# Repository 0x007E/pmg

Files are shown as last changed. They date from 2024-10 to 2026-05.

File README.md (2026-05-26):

  

# `PMG` - Audio Level Meter (Pegelmessgerät)

The `pmg` project is based on a pcb with an elektret microphone signal transistor (`BC547`) amplifier and a transistor stage for level signalization.

| Experience | Level |
|:---|:-----:|
| Soldering | 50% |
| Mechanical  | 50% |

# Downloads

| Type | File | Description |
|:---:|:---:|:---|
| Simulation | [asc](https://github.com/0x007E/pmg/raw/refs/heads/main/PMG.asc) | LTSpice Simulation | 
| Lochmaster | [lm4](https://github.com/0x007E/pmg/raw/refs/heads/main/PMG.LM4) | Stripe grid circuit board | 
| Schematic | [pdf](https://github.com/0x007E/pmg/releases/latest/download/schematic.pdf) / [cadlab](https://cadlab.io/project/28569/main/files) | Schematic files |
| Board | [pdf](https://github.com/0x007E/pmg/releases/latest/download/pcb.pdf) / [cadlab](https://cadlab.io/project/28569/main/files) | Board file |
| Drill | [pdf](https://github.com/0x007E/pmg/releases/latest/download/drill.pdf) | Drill file |
| BoM | [xlsx](https://github.com/0x007E/pmg/releases/latest/download/bom.xlsx) / [html](https://github.com/0x007E/pmg/releases/latest/download/bom.html) | Bill of Material as Excel/interactive HTML |
| PCB | [zip](https://github.com/0x007E/pmg/releases/latest/download/kicad.zip) / [tar](https://github.com/0x007E/pmg/releases/latest/download/kicad.tar.gz) | KiCAD/Gerber/BoM/Drill files |
| Mechanical | [zip](https://github.com/0x007E/pmg/releases/latest/download/freecad.zip) / [tar](https://github.com/0x007E/pmg/releases/latest/download/freecad.tar.gz) | FreeCAD/Housing and PCB (STEP/STL) files |

# Hardware

There are two parts of the hardware. The pcb and the housing of the `PMG`. The pcb is created with `KiCAD` and the housing with `FreeCAD`. All files are built with `github actions` so that they are ready for a production environment. The housing is printed with a 3D-printer (`Dremel 3D40`).

## PCB

The circuit board is populated on one side (Top). The best way for soldering is within a standard soldering system.

### Top Layer

Top Layer

### Bottom Layer

Bottom Layer

## Mechanical

The housing has a tolerance of `0.2mm` on each side of the case. So the pcb should fit perfectly in the housing. The tolerance can be modified with `FreeCAD` in the `Parameter` Spreadsheet.

### Assembled

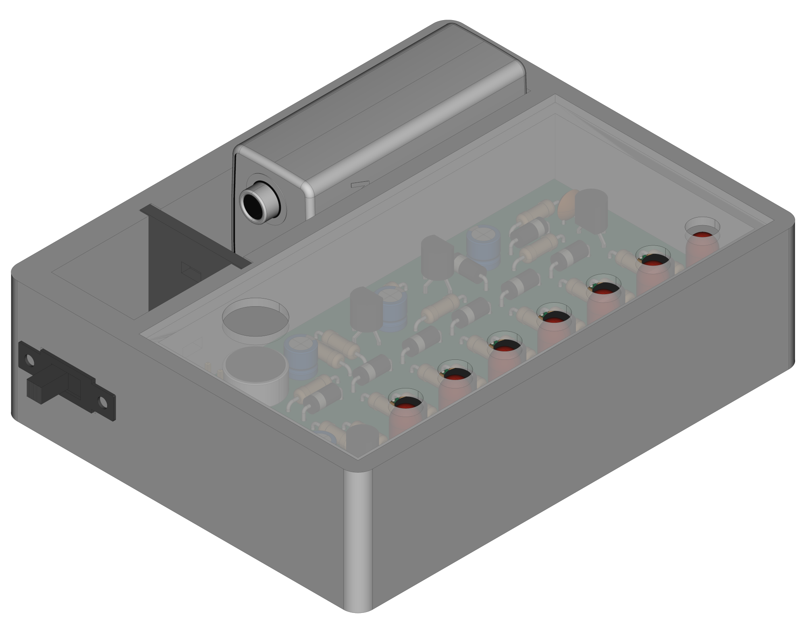
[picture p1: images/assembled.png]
Assembled


#### Exploded

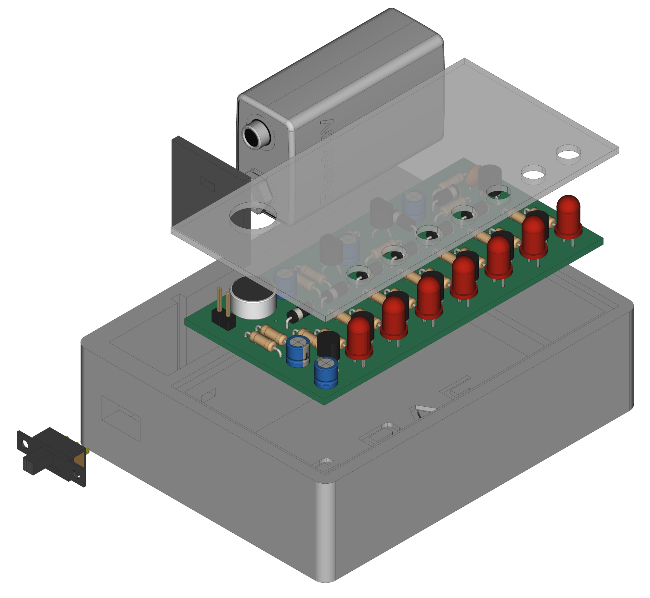
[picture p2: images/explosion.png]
Exploded


# Additional Information

| Type | Link | Description |
|:---:|:---:|:---|
| BC547 | [pdf](https://www.sparkfun.com/datasheets/Components/BC546.pdf) | NPN Transistor |

---

R. GAECHTER

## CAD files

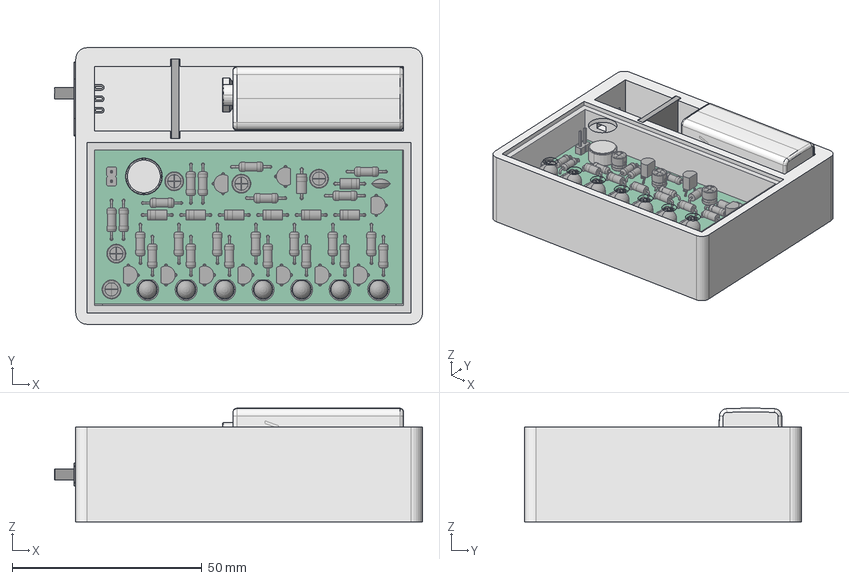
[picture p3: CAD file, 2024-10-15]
mechanical/housing.FCStd
97.1 x 73.0 x 30.0 mm
AcrylGlass
Separator
Switch
9VBlock
Pcb_1d7d
Q7_TO-92_Wide_4bfbe9c5f8f4
C6_C_Disc_D50mm_W25mm_P250mm_441e31f26d57
D14_D_A-405_P7.62mm_Horizontal_84994ef9fd34
R22_R_Axial_DIN0207_L63mm_D25mm_P1016mm_Horizontal_d8874ca5abab
R15_R_Axial_DIN0207_L63mm_D25mm_P1016mm_Horizontal_26bb8defbff6
D3_LED_D5.0mm_3ee2d2edeb13
Q8_TO-92_Wide_a93fba4ea393
Q1_TO-92_Wide_c0447f71f260
D4_LED_D5.0mm_dc1b8127458c
Q9_TO-92_Wide_263e551227a1
R14_R_Axial_DIN0207_L63mm_D25mm_P1016mm_Horizontal_b1f9f71ed35f
R13_R_Axial_DIN0207_L63mm_D25mm_P1016mm_Horizontal_caadc2475899
R8_R_Axial_DIN0207_L63mm_D25mm_P1016mm_Horizontal_83ed933a83d2
R2_R_Axial_DIN0207_L63mm_D25mm_P1016mm_Horizontal_2cb8f415b4d6
R1_R_Axial_DIN0207_L63mm_D25mm_P1016mm_Horizontal_401779ecf60e
MK1_CUI_DEVICES_CMA-4544PF-W_7a05e5a25c01
D15_D_A-405_P7.62mm_Horizontal_00f129ff81aa
D12_D_A-405_P7.62mm_Horizontal_3dac00b416f9
Q5_TO-92_Wide_fe35382576d2
Q6_TO-92_Wide_d52b6dc564fe
R12_R_Axial_DIN0207_L63mm_D25mm_P1016mm_Horizontal_3b9f8811e661
D11_D_A-405_P7.62mm_Horizontal_5c6651d95b19
R3_R_Axial_DIN0207_L63mm_D25mm_P1016mm_Horizontal_a9c3d9380691
D6_LED_D5.0mm_595b68b19a06
R20_R_Axial_DIN0207_L63mm_D25mm_P1016mm_Horizontal_8b5b8a0e60e4
R18_R_Axial_DIN0207_L63mm_D25mm_P1016mm_Horizontal_3c62972e58e7
D5_LED_D5.0mm_60034bc3a21b
C1_CP_Radial_D50mm_P250mm_23c4ec5917c1
C2_CP_Radial_D50mm_P250mm_5b7aa9b1d5d5
R21_R_Axial_DIN0207_L63mm_D25mm_P1016mm_Horizontal_043bab5f4419
C5_CP_Radial_D50mm_P250mm_fa609370bd94
R6_R_Axial_DIN0207_L63mm_D25mm_P1016mm_Horizontal_0dea557aebe9
R7_R_Axial_DIN0207_L63mm_D25mm_P1016mm_Horizontal_5a96a4f1f65e
R4_R_Axial_DIN0207_L63mm_D25mm_P1016mm_Horizontal_78e21f6ad2d1
Q4_TO-92_Wide_d99fa3e43c21
R16_R_Axial_DIN0207_L63mm_D25mm_P1016mm_Horizontal_4811e6ad3072
C3_CP_Radial_D50mm_P250mm_dfde33150532
J3_PinHeader_1x02_P254mm_Vertical_e5993ac934dd
R9_R_Axial_DIN0207_L63mm_D25mm_P1016mm_Horizontal_532797f5b529
D9_D_A-405_P7.62mm_Horizontal_a4ace171a1cc
R19_R_Axial_DIN0207_L63mm_D25mm_P1016mm_Horizontal_3230d582ee0a
R10_R_Axial_DIN0207_L63mm_D25mm_P1016mm_Horizontal_891c64406b5c
R17_R_Axial_DIN0207_L63mm_D25mm_P1016mm_Horizontal_3e8b808dfa95
Q3_TO-92_Wide_e69642412aa5
D2_LED_D5.0mm_370cab26fe4a
Q10_TO-92_Wide_6694c14d1b8c
D7_LED_D5.0mm_994bed6c4edc
D8_D_A-405_P7.62mm_Horizontal_a44a823cf9d3
R11_R_Axial_DIN0207_L63mm_D25mm_P1016mm_Horizontal_5143b20dbc7e
Q2_TO-92_Wide_83d40f09d7ee
D10_D_A-405_P7.62mm_Horizontal_c6f234e0c10f
R23_R_Axial_DIN0207_L63mm_D25mm_P1016mm_Horizontal_4c4d199288b2
D1_LED_D5.0mm_5167b579a80a
C4_CP_Radial_D50mm_P250mm_2689a81529ee
R5_R_Axial_DIN0207_L63mm_D25mm_P1016mm_Horizontal_431b73a015bb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

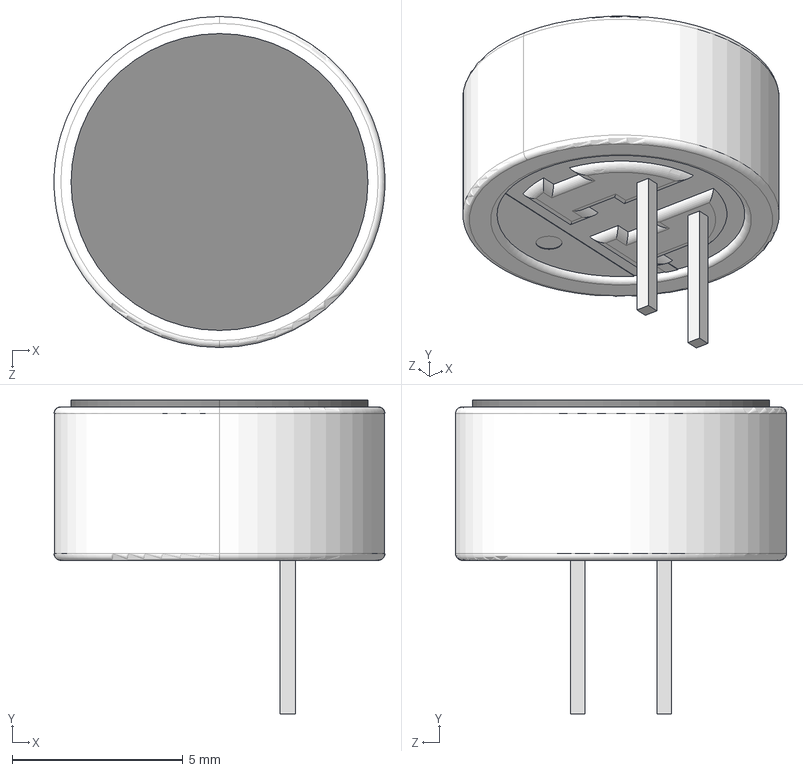
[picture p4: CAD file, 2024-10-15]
pcb/CUI_DEVICES_CMA-4544PF-W.step
9.70 x 9.20 x 9.70 mm

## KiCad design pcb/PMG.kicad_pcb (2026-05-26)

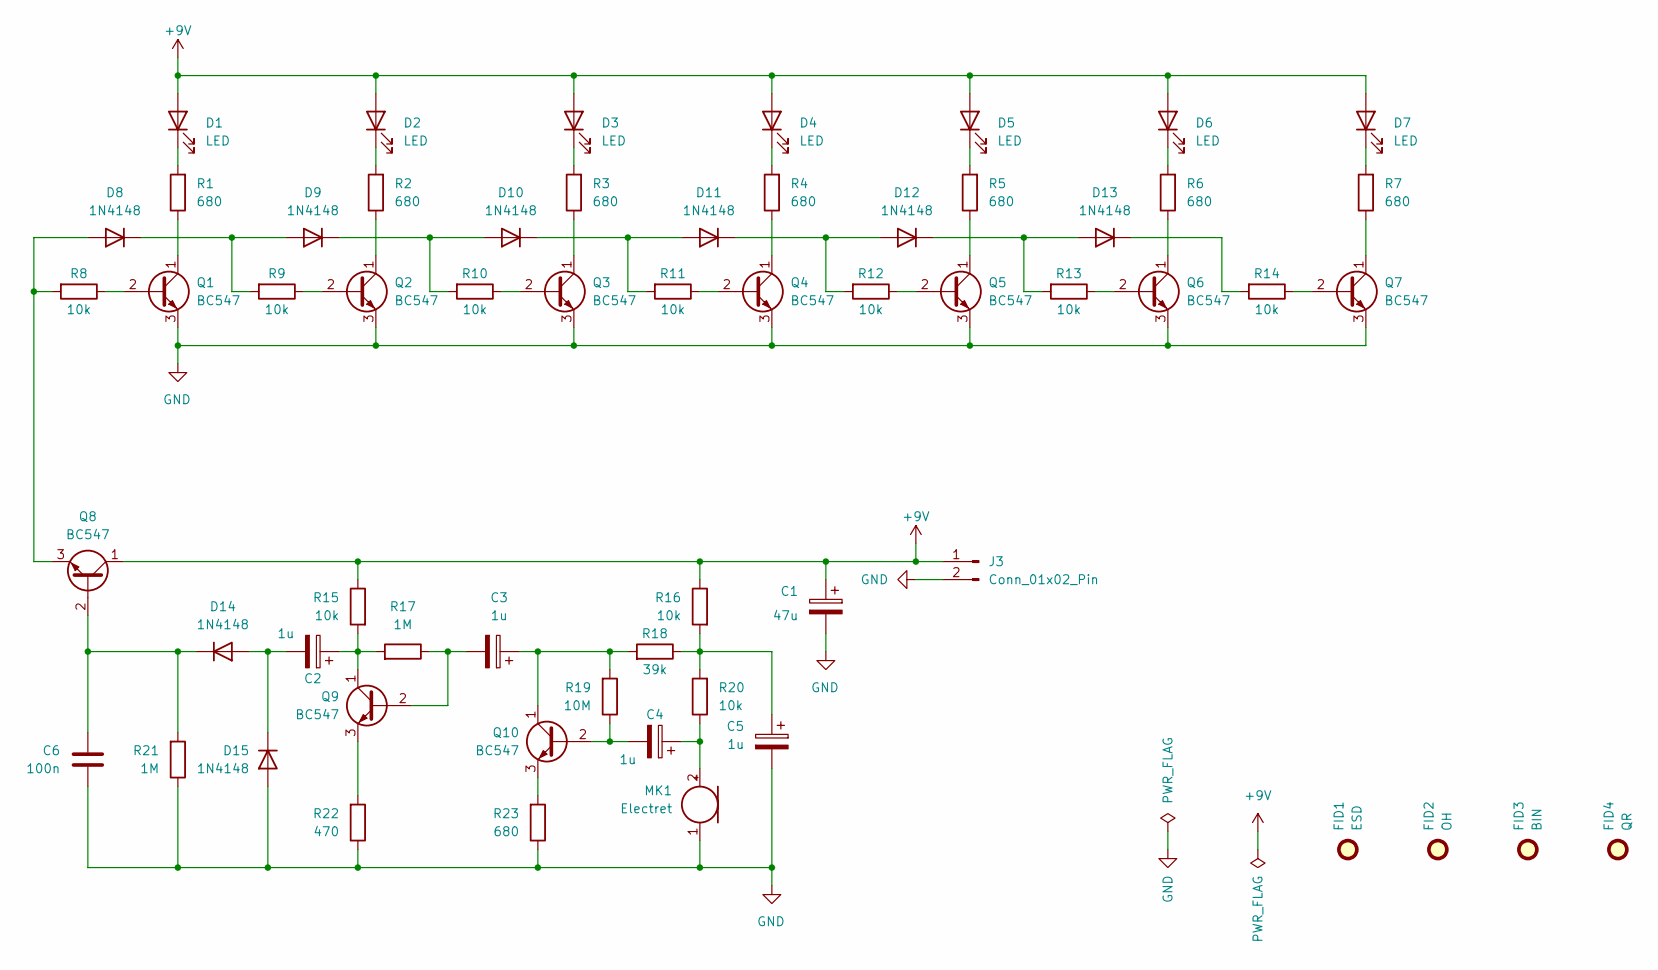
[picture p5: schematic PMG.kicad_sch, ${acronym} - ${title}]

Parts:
C1: 47u; CP_Radial_D5.0mm_P2.50mm
C2, C3, C4, C5: 1u; CP_Radial_D5.0mm_P2.50mm
C6: 100n; C_Disc_D5.0mm_W2.5mm_P2.50mm
D1, D2, D3, D4, D5, D6, D7: LED; LED_D5.0mm
D8, D9, D10, D11, D12, D13, D14, D15: 1N4148; D_A-405_P7.62mm_Horizontal
FID1: ESD; ESD-Logo_6.6x6mm_SilkScreen
FID2: OH; OSHW-Logo2_7.3x6mm_SilkScreen
FID3: BIN; WEEE-Logo_4.2x6mm_SilkScreen
FID4: QR; QR_0x007e_small
J3: Conn_01x02_Pin; PinHeader_1x02_P2.54mm_Vertical
MK1: Electret; Electret_THT
Q1, Q2, Q3, Q4, Q5, Q6, Q7, Q8, Q9, Q10: BC547; TO-92_Wide
R1, R2, R3, R4, R5, R6, R7, R23: 680; R_Axial_DIN0207_L6.3mm_D2.5mm_P10.16mm_Horizontal
R8, R9, R10, R11, R12, R13, R14, R15, R16, R20: 10k; R_Axial_DIN0207_L6.3mm_D2.5mm_P10.16mm_Horizontal
R17, R21: 1M; R_Axial_DIN0207_L6.3mm_D2.5mm_P10.16mm_Horizontal
R18: 39k; R_Axial_DIN0207_L6.3mm_D2.5mm_P10.16mm_Horizontal
R19: 10M; R_Axial_DIN0207_L6.3mm_D2.5mm_P10.16mm_Horizontal
R22: 470; R_Axial_DIN0207_L6.3mm_D2.5mm_P10.16mm_Horizontal

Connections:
+9V: C1.1, D1.2 (A), D2.2 (A), D3.2 (A), D4.2 (A), D5.2 (A), D6.2 (A), D7.2 (A), J3.1, Q8.1 (C), R15.1, R16.1
GND: C1.2, C5.2, C6.2, D15.2 (A), J3.2, MK1.1 (-), Q1.3 (E), Q2.3 (E), Q3.3 (E), Q4.3 (E), Q5.3 (E), Q6.3 (E), Q7.3 (E), R21.1, R22.1, R23.1
unnamed: C5.1, R16.2, R18.1, R20.2
unnamed: D1.1 (K), R1.2
unnamed: D2.1 (K), R2.2
unnamed: D3.1 (K), R3.2
unnamed: D4.1 (K), R4.2
unnamed: D5.1 (K), R5.2
unnamed: D6.1 (K), R6.2
unnamed: D7.1 (K), R7.2
unnamed: D8.2 (A), Q8.3 (E), R8.2
unnamed: D8.1 (K), D9.2 (A), R9.2
unnamed: D9.1 (K), D10.2 (A), R10.2
unnamed: D10.1 (K), D11.2 (A), R11.2
unnamed: D11.1 (K), D12.2 (A), R12.2
unnamed: D12.1 (K), D13.2 (A), R13.2
unnamed: D13.1 (K), R14.2
unnamed: C2.2, D14.2 (A), D15.1 (K)
unnamed: C6.1, D14.1 (K), Q8.2 (B), R21.2
unnamed: C4.1, MK1.2 (+), R20.1
unnamed: Q1.2 (B), R8.1
unnamed: Q1.1 (C), R1.1
unnamed: Q2.2 (B), R9.1
unnamed: Q2.1 (C), R2.1
unnamed: Q3.2 (B), R10.1
unnamed: Q3.1 (C), R3.1
unnamed: Q4.2 (B), R11.1
unnamed: Q4.1 (C), R4.1
unnamed: Q5.2 (B), R12.1
unnamed: Q5.1 (C), R5.1
unnamed: Q6.2 (B), R13.1
unnamed: Q6.1 (C), R6.1
unnamed: Q7.2 (B), R14.1
unnamed: Q7.1 (C), R7.1
unnamed: C3.2, Q9.2 (B), R17.1
unnamed: C2.1, Q9.1 (C), R15.2, R17.2
unnamed: Q9.3 (E), R22.2
unnamed: C4.2, Q10.2 (B), R19.1
unnamed: C3.1, Q10.1 (C), R18.2, R19.2
unnamed: Q10.3 (E), R23.2

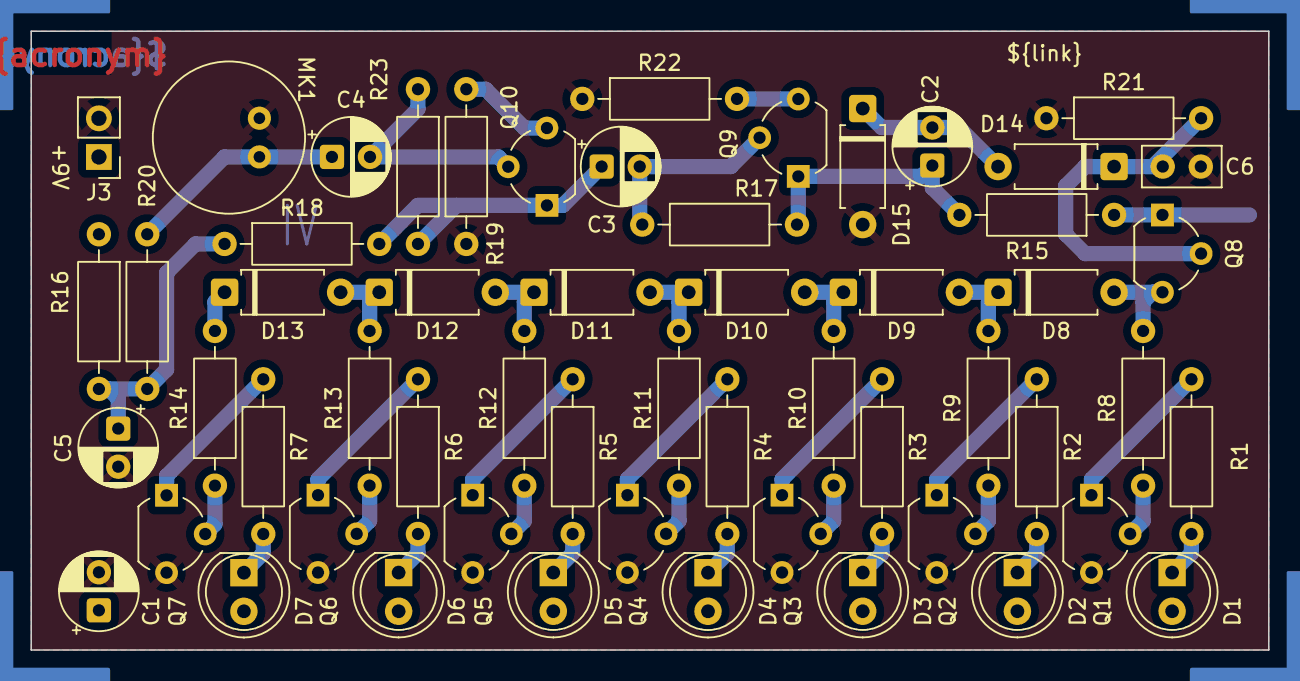
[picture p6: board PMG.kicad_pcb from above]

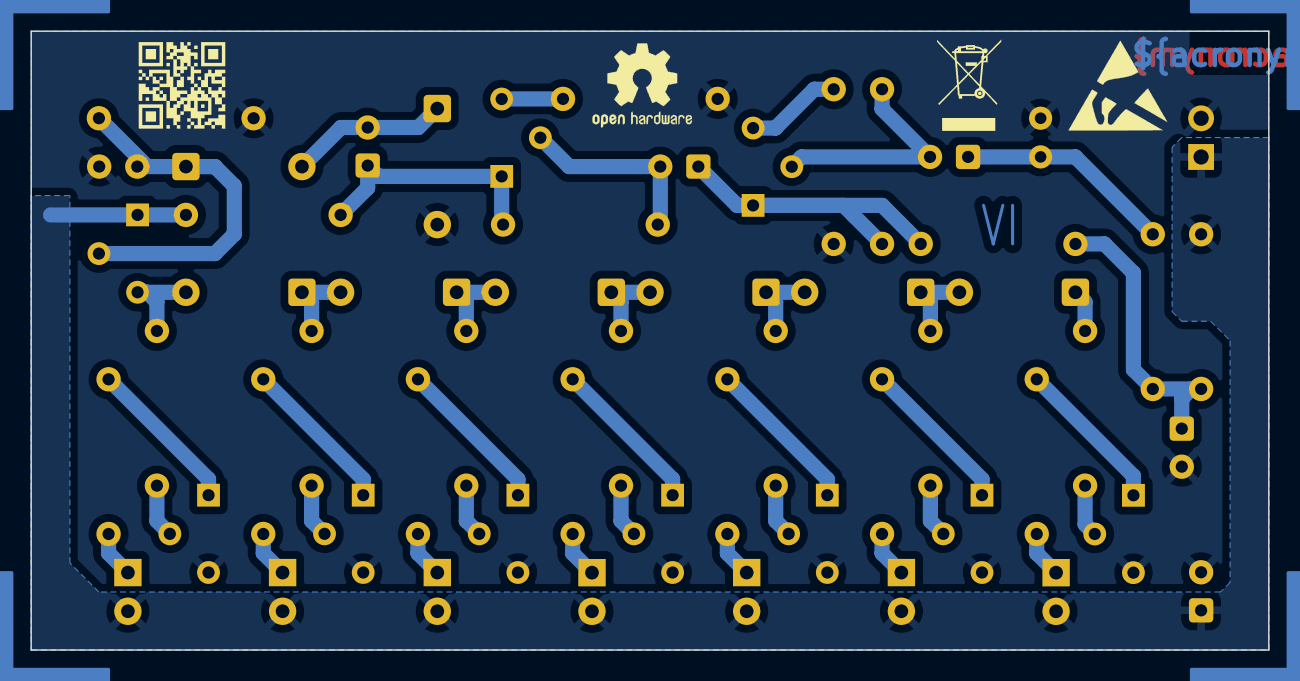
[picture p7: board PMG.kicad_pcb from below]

Board: 2 copper layers, 81.3 x 40.6 mm, 60 parts (4 on the bottom side), 40 nets.

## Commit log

2026-05-26 Update to KiCAD 9
    [PMG.kicad_pcb, PMG.kicad_sch]
2026-05-26 Rename/Remove bom fields
    [PMG.kicad_pcb, PMG.kicad_sch]

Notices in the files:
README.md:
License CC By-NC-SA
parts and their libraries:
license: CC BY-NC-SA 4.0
